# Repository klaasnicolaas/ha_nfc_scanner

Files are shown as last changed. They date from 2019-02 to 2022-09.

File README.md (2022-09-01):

# NFC Scanner :mag: for Home Assistant :house:

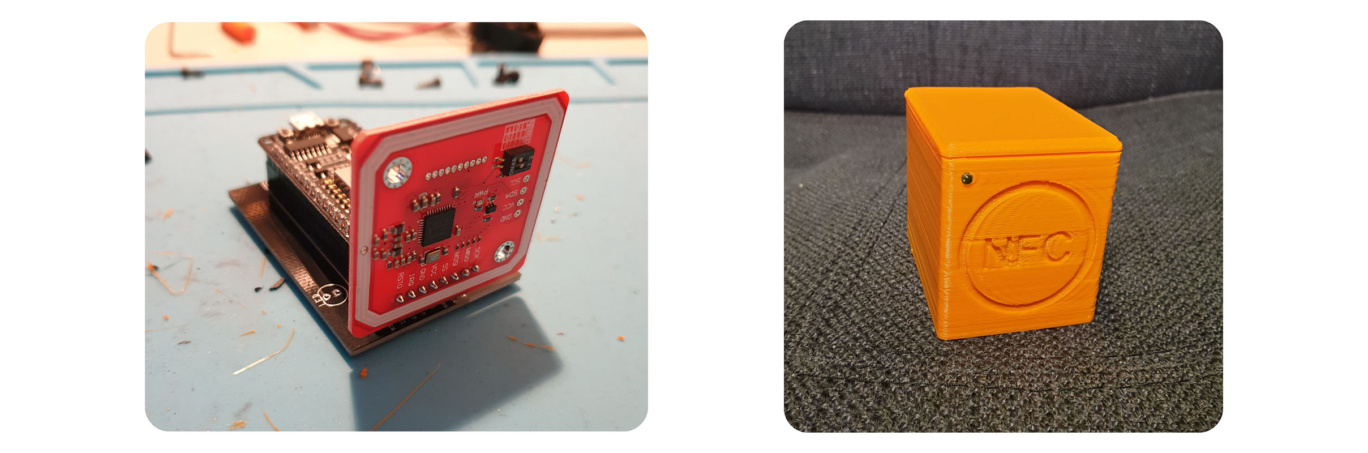
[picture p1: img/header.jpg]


## About

Imagine that you could start or stop everything with a NFC tag in Home Assistant :smile: Every time you hold an NFC tag against the scanner (and the UID of it is included in the list), there will be send an MQTT message to your broker and eventually to Home Assistant. With a LED you also get physical feedback, that the scanner has actually recognized your Tag. Recently I have added the feature to use Over The Air(OTA) updates, with password protection.

For the NFC scanner I designed a circuit board (PCB) and a 3D printed case.

- In the `case` folder you will find the required STL files.
- In the `pcb` folder you can find the Gerber files. Many people let their boards made by [Seeedstudio](https://www.seeedstudio.com/fusion_pcb.html) in Shenzhen.
- In the `img` folder some pictures of the project.

If you have suggestions or questions, open an **issue** or contribute via a **PR**!

### Schematic

Requirements:

- PN532 NFC RFID (Elechouse module v3) - [Banggood][pn532-bg-shop] or [AliExpress][pn532-ali-shop]
- ESP8266 (NodeMCU v1.0) - [Banggood][esp8266-bg-shop] or [AliExpress][esp8266-ali-shop]

| NFC reader | NodeMCU / ESP8266  |
|---|---|
| SS (CS) | D2 (GPIO4) |
| SCK | D5 (GPIO14) |
| MISO | D6 (GPIO12) |
| MOSI | D7 (GPIO13) |
| VCC | VCC (3V3) |
| GND | GND |

## How to setup

- You need Arduino IDE to configure some files, and use the serial monitor (other IDE's are okey).
- You need the `PN532`, `PubSubClient`, `SPI` and `ESP8266WiFi` library.

Further down this page you will find all information about which adjustments you have to make.

### NFC Tags

At `NUM_ACCEPTED_UIDS` you indicate how many NFC tags/cards you will use. Then enter the `UID` values of your NFC tags/cards and give each tag/card its own name. If you are going to make multiple nfc scanners, you can indicate in which room the scanner is present with the `LOCATION` variable.

```C++
#define NUM_ACCEPTED_UIDS 2 //<-----------------CHANGE THIS IF ADDING CARDS!!
NFCTag NFCTags[NUM_ACCEPTED_UIDS] = {
  // It is neccessary to account for UID length since a 7 byte ID could contain a 4 byte ID, which would cause a misfire
 //  #0    #1    #2    #3    #4    #5    #6   #Tagname
  {{0x00, 0x00, 0x00, 0x00, 0x00, 0x00, 0x00}, "Tag1", false, 0, false, {0}},
  {{0x00, 0x00, 0x00, 0x00, 0x00, 0x00, 0x00}, "Tag2", false, 0, false, {0}},
};

// Location of the NFC scanner
#define LOCATION "living_room"
```

#### Finding the UIDs

You can find your `UID` value in different ways, such as via your phone through certain apps from the app / play store. But to make it easy for yourself, it is possible to read only the UID tags / cards, via the same .ino script.

You start this mode by setting `readUIDMode` to true, in the **`ha_nfc_scanner.ino`** file.

```C++
// False wil start de main function, True will start the UID read script so you can find out wich UID's your NFC tags have on the serial monitor.
bool readUIDMode = true;
```

This way the MQTT and WIFI are switched off and you can read your UID values using the serial monitor.

### Credentials

Enter the details of your Wi-Fi network and login details of your MQTT client account and the IP address of the MQTT broker. Also provide a hostname and password for the Over The Air(OTA) feature.

```c++
// OTAupdate
#define OTA_HOSTNAME      ""
#define OTA_PASSWORD      ""

// Wi-Fi credentials
#define WIFI_SSID         ""
#define WIFI_PASSWORD     ""

// MQTT
#define MQTT_USERNAME     ""
#define MQTT_PASSWORD     ""
#define MQTT_SERVER       ""
#define MQTT_SERVER_PORT  1883
```

### Home Assistant - Binary Sensor

in Home Assistant we can create a binary sensor that will respond when a tag is recognized and is in the UID list.

To retrieve and use the results obtained with the NFC scanner into Home Assistant, please edit and add this snippet into your configuration. Make sure to replace `<CHIP_ID`, `<LOCATION>` and `<NFC_TAG_NAME>` with the values defined in `config.h`.

```yaml
# Example configuration.yaml entry
binary_sensor:
  - platform: mqtt
    name: 'NFC Tag 1'
    state_topic: '<CHIP_ID>/sensor/<LOCATION>/<NFC_TAG_NAME>/state'
    availability_topic: '<CHIP_ID>/availability'
  - platform: mqtt
    name: 'NFC Tag 2'
    state_topic: '<CHIP_ID>/sensor/<LOCATION>/<NFC_TAG_NAME>/state'
    availability_topic: '<CHIP_ID>/availability'
```

### PCB Design

Do you live in the Netherlands and you want a PCB? Contact me I have number of PCB's.

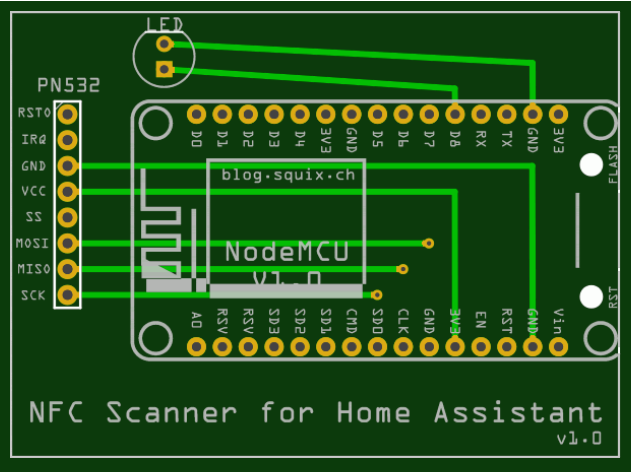
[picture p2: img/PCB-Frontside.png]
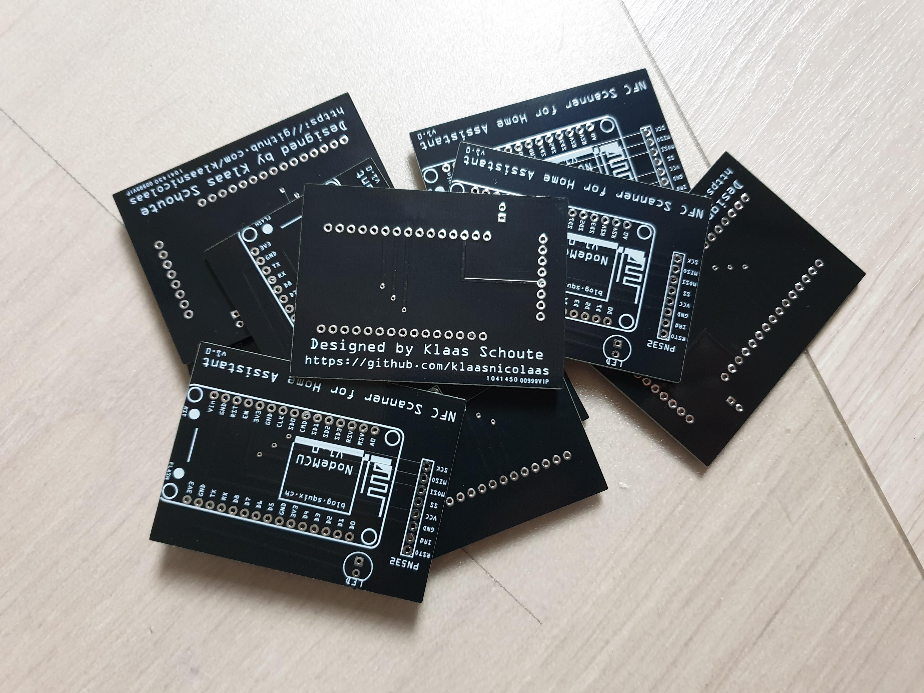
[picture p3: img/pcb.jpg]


## Troubleshooting

If you get an error, create then an **issue** so that I can sort things out for you. Below the solution for errors that I have encountered.

### Not Enough Space

If you get the error message `[ERROR]: Bad Answer: ERR: ERROR[4]: Not Enough Space`, change in the Arduino IDE the *Flash Size* to `4M (1M SPIFFS)`.

## Credits

A big :star: for [mertenats](https://github.com/mertenats/Open-Home-Automation), the script of this repo is based on his.

## Disclamer

We use aliexpress / banggood affiliate links for the components and the tools. Some Ad-blockers might block these links an thus they seem to appear broken. You will have to temporarely disable ad-blocker to open these links.

## License

MIT License

Copyright (c) 2019-2022 Klaas Schoute

Permission is hereby granted, free of charge, to any person obtaining a copy
of this software and associated documentation files (the "Software"), to deal
in the Software without restriction, including without limitation the rights
to use, copy, modify, merge, publish, distribute, sublicense, and/or sell
copies of the Software, and to permit persons to whom the Software is
furnished to do so, subject to the following conditions:

The above copyright notice and this permission notice shall be included in all
copies or substantial portions of the Software.

THE SOFTWARE IS PROVIDED "AS IS", WITHOUT WARRANTY OF ANY KIND, EXPRESS OR
IMPLIED, INCLUDING BUT NOT LIMITED TO THE WARRANTIES OF MERCHANTABILITY,
FITNESS FOR A PARTICULAR PURPOSE AND NONINFRINGEMENT. IN NO EVENT SHALL THE
AUTHORS OR COPYRIGHT HOLDERS BE LIABLE FOR ANY CLAIM, DAMAGES OR OTHER
LIABILITY, WHETHER IN AN ACTION OF CONTRACT, TORT OR OTHERWISE, ARISING FROM,
OUT OF OR IN CONNECTION WITH THE SOFTWARE OR THE USE OR OTHER DEALINGS IN THE
SOFTWARE.

[scanner-stack]: /img/nfc-scanner-stack.jpg

<!-- Hardware -->
[esp8266-bg-shop]: https://www.banggood.com/bang/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
[esp8266-ali-shop]: https://tc.tradetracker.net/?c=15640&m=12&a=417111&r=&u=%2Fitem%2F4000160133215.html
[pn532-bg-shop]: https://www.banggood.com/bang/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
[pn532-ali-shop]: https://tc.tradetracker.net/?c=15640&m=12&a=417111&r=&u=%2Fitem%2F1005001561633575.html

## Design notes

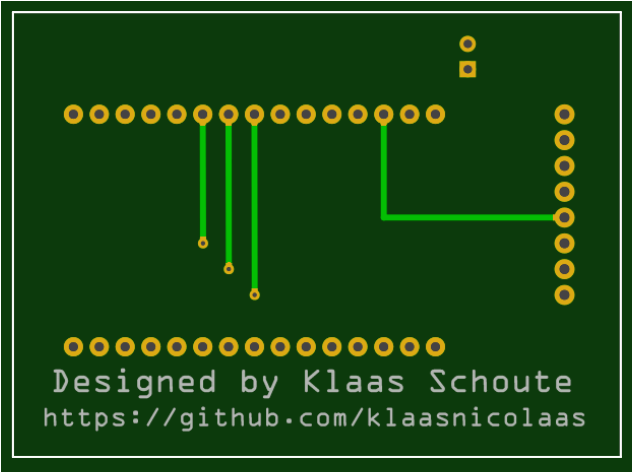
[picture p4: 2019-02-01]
img/PCB-Backside.png

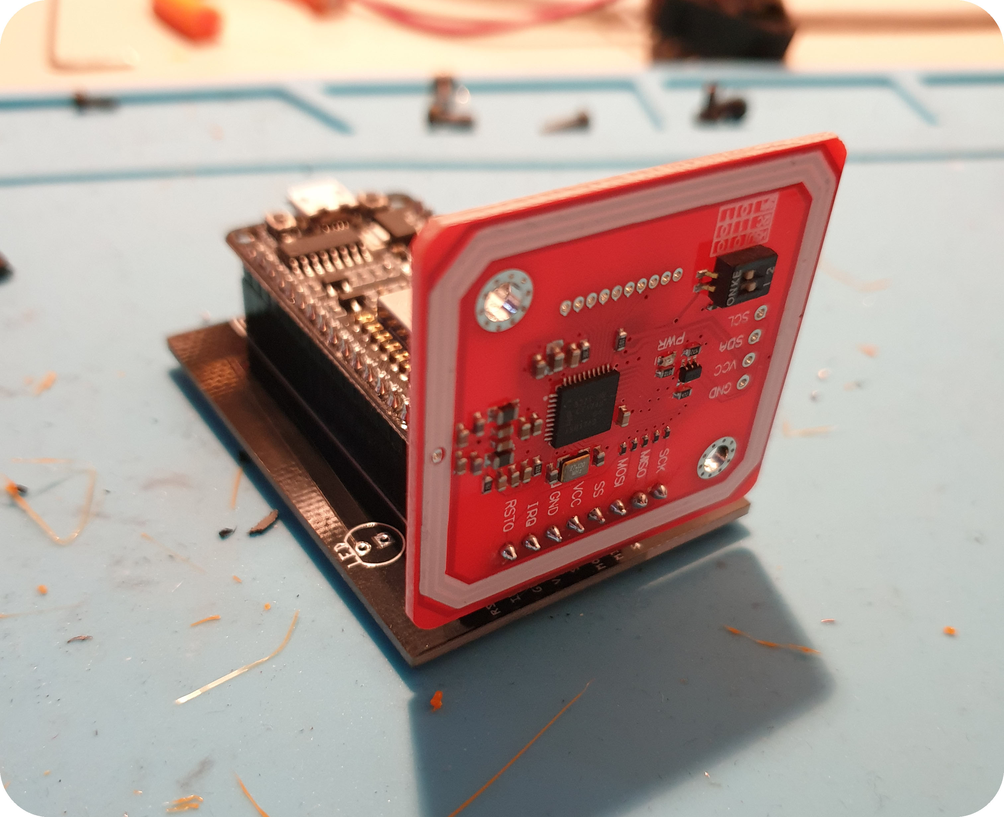
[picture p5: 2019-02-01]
img/nfc-scanner-stack.jpg

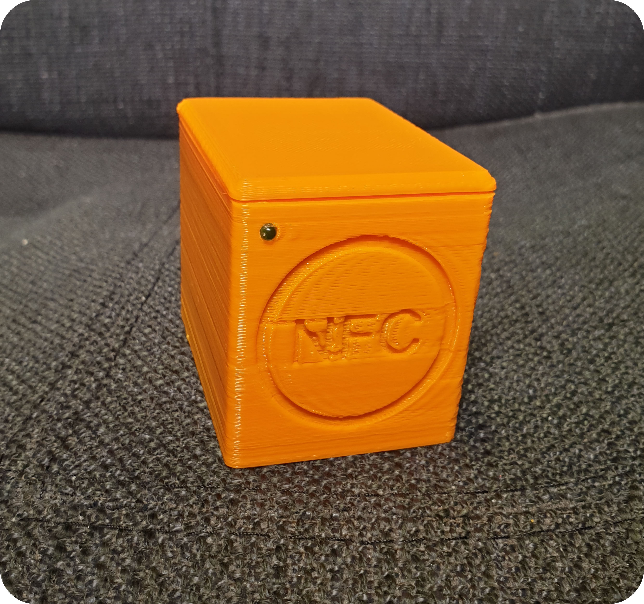
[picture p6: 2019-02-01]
img/case.jpg

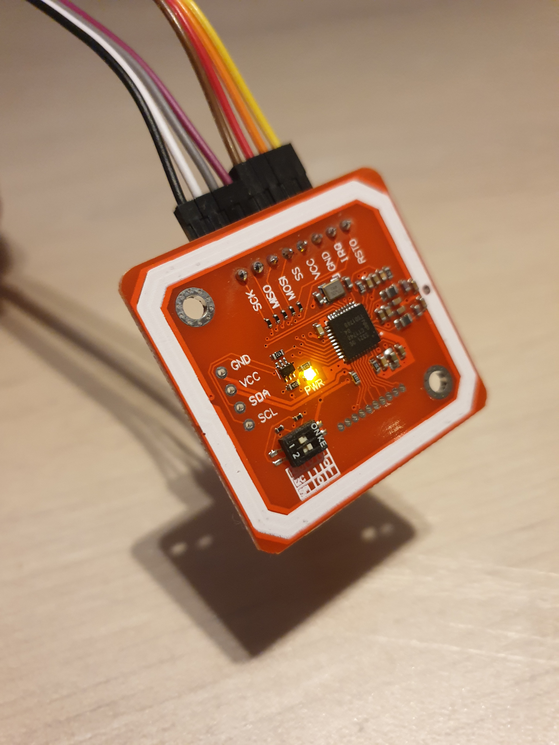
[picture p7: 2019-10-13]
img/pn532.jpg

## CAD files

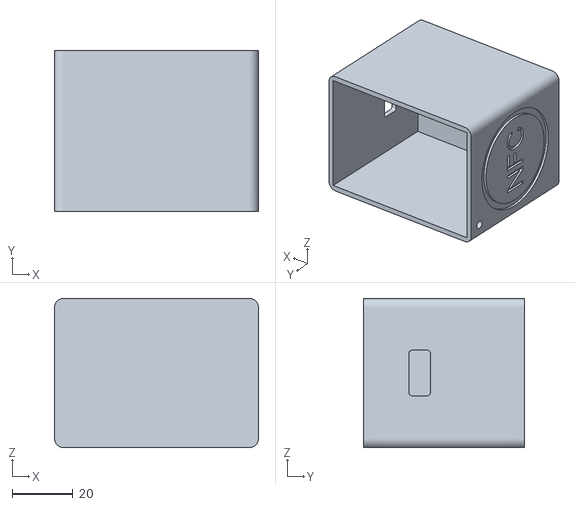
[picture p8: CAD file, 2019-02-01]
case/NFC Scanner box v1.1.stl
67.0 x 53.0 x 49.0

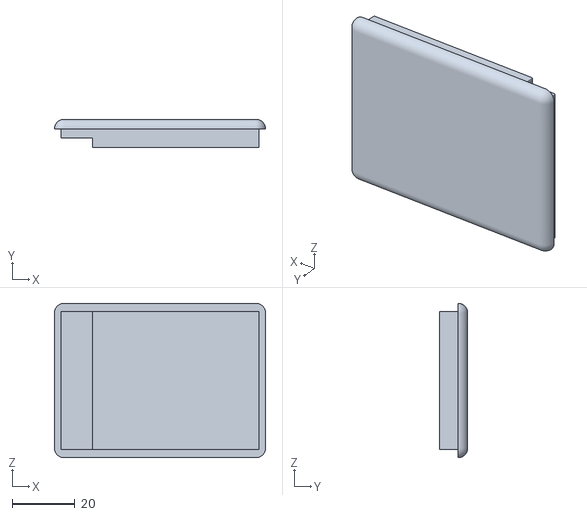
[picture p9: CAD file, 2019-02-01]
case/NFC Scanner box - Cover v1.3.stl
67.0 x 9.00 x 49.0

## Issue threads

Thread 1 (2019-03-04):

PCB to Germany

TheZoker, 2019-03-04:
Awesome NFC project!
I know not really an issue, but the best way to contact you

Just wondering if you would also send these PCBs that you made to Germany? 😃

klaasnicolaas, 2019-03-04:
You can contact me directly via Discord (Mister Nicolaz#7558), [Twitter](https://twitter.com/klaasnicolaas) or email on my Github profile.

Then we will see what is possible.

Closed 2019-03-05.

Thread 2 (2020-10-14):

NFCTag erro - Noob help

kekec777, 2020-10-14:
Hi

First i want to say , that im new to this , so please be patient with me :)

I want to make a nfc scanner and have bought :
PN532 NFC RFID (Elechouse module v3)
ESP8266 (NodeMCU v1.0)

and have printed the case in 3D.

BUT when i try to compile (in Arduino) this:

`#define NUM_ACCEPTED_UIDS 1 //<-----------------CHANGE THIS IF ADDING CARDS!!
NFCTag NFCTags[NUM_ACCEPTED_UIDS] = {
  // It is neccessary to account for UID length since a 7 byte ID could contain a 4 byte ID, which would cause a misfire
 //  #0    #1    #2    #3    #4    #5    #6   #Tagname
  {{0x00, 0x00, 0x00, 0x00, 0x00, 0x00, 0x01}, "Tag1", false, 0, false, {0}},
};

// send OFF payload after x ms
#define MAX_NON_DISCOVERED_PERIOD 500

// Location of the BLE scanner
#define LOCATION "living_room"

`

i get an error :
error: 'NFCTag' does not name a type
 NFCTag NFCTags[NUM_ACCEPTED_UIDS] = {
 ^
exit status 1
'NFCTag' does not name a type

I have added PN532 and PubSubClient in Arduino\libraries manually , but  SPI and ESP8266WiFi i couldt find?
I tried to search in Arduino Libraries and added some i thought sounded right.

Maybe a noob guide?
or any kind of input :)

thanks in advise

klaasnicolaas, 2020-10-21:
Unfortunately, I cannot help you with that at the moment, everything is still packed due to a move. As a result, I am now unable to debug it myself 😢

kekec777, 2020-12-15:
Thanks for the reply - and sorry for the late answer :)
I was also moving :)
When do you think you can debug it?

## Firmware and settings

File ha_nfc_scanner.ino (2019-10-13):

/*
  NFC Scanner for Home Assistant
  
  Libraries:
    - PubSubClient: https://github.com/knolleary/pubsubclient
    - PN532:        https://github.com/Seeed-Studio/PN532

  Release Notes:
  Klaas S. - V1.2 - 10.2019
  - Add OTA update feature

  Klaas S. - V1.1 - 02.2019
  - By means of an LED you can now see if the ESP recognizes an NFC tag.
  - Fix use of 7 bytes nfc tags.
  - Add option to use reading UID's only or not.
  
  Samuel M. - v1.0 - 02.2018
  - Initial script that is made by: https://github.com/mertenats/open-home-automation
*/

typedef struct {
  uint8_t uid[8];
  String  tagName;
  bool    isDiscovered;
  long    lastDiscovery;
  bool    toNotify;
  char    mqttTopic[48];
} NFCTag;

#include "config.h"
#include <ESP8266WiFi.h>
#include <ArduinoOTA.h>
#include <SPI.h>
#include <PN532_SPI.h>
#include "PN532.h"        // https://github.com/Seeed-Studio/PN532
#include <PubSubClient.h> // https://github.com/knolleary/pubsubclient

#if defined(DEBUG_SERIAL)
#define     DEBUG_PRINT(x)    Serial.print(x)
#define     DEBUG_PRINTLN(x)  Serial.println(x)
#else
#define     DEBUG_PRINT(x)
#define     DEBUG_PRINTLN(x)
#endif

WiFiClient    wifiClient;
PubSubClient  mqttClient(wifiClient);
PN532_SPI     pn532spi(SPI, 4);
PN532         nfc(pn532spi);

int ledPin = 15;
// False wil start de main function, True will start the UID read script so you can find out wich UID's your NFC tags have on the serial monitor.
bool readUIDMode = false;

///////////////////////////////////////////////////////////////////////////
//   Read NFC as sensor for HA 
///////////////////////////////////////////////////////////////////////////
void readNFCTag() {
  uint8_t uid[] = { 0, 0, 0, 0, 0, 0, 0, 0 };  // Buffer to store the returned UID
  uint8_t uidLength; // Length of the UID (4 or 7 bytes depending on ISO14443A card type)
  
  if (nfc.readPassiveTargetID(PN532_MIFARE_ISO14443A, uid, &uidLength)) {
    for (uint8_t i = 0; i < NUM_ACCEPTED_UIDS; i++) {
      if (strcmp((char *)uid, (char *)NFCTags[i].uid) == 0) {
        if (!NFCTags[i].isDiscovered) {
          NFCTags[i].isDiscovered = true;
          NFCTags[i].toNotify = true;
          digitalWrite(ledPin, HIGH);
        }
        NFCTags[i].lastDiscovery = millis();
        break;
      }
    }
  }
  
  for (uint8_t i = 0; i < NUM_ACCEPTED_UIDS; i++) {
    if (NFCTags[i].isDiscovered == true && NFCTags[i].lastDiscovery + MAX_NON_DISCOVERED_PERIOD < millis()) {
      NFCTags[i].isDiscovered = false;
      NFCTags[i].toNotify = true;
      digitalWrite(ledPin, LOW);
    }
  }
}

///////////////////////////////////////////////////////////////////////////
//   Read NFC UID's  
///////////////////////////////////////////////////////////////////////////
void readUID() {
  boolean success;
  uint8_t uidLength;   // Length of the UID (4 or 7 bytes depending on ISO14443A card type)
  uint8_t uid[] = { 0, 0, 0, 0, 0, 0, 0 };  // Buffer to store the returned UID

  // Wait for an ISO14443A type cards (Mifare, etc.).  When one is found
  // 'uid' will be populated with the UID, and uidLength will indicate
  // if the uid is 4 bytes (Mifare Classic) or 7 bytes (Mifare Ultralight)
  success = nfc.readPassiveTargetID(PN532_MIFARE_ISO14443A, &uid[0], &uidLength);

  if (success) {
    digitalWrite(ledPin, HIGH);
    Serial.println("\n-----------\n");
    Serial.println("Found a card!");
    Serial.print("UID Length: ");
    Serial.print(uidLength, DEC);
    Serial.println(" bytes");
    Serial.print("UID Value: ");
    delay(1000);
    digitalWrite(ledPin, LOW);

    for (uint8_t i=0; i < uidLength; i++) {
      Serial.print(" 0x");
      Serial.print(uid[i], HEX);
    }

    // wait until the card is taken away
    while (nfc.readPassiveTargetID(PN532_MIFARE_ISO14443A, &uid[0], &uidLength)) {
      yield(); //let ESPcore handle wifi stuff
    }
    
    Serial.println("\n-----------\n");
  }
  else yield(); // PN532 probably timed out waiting for a card.. let's let the ESPcore handle wifi stuff
}
///////////////////////////////////////////////////////////////////////////
//   WiFi
///////////////////////////////////////////////////////////////////////////
/*
   Function called to handle WiFi events
*/
void handleWiFiEvent(WiFiEvent_t event) {
  switch (event) {
    case WIFI_EVENT_STAMODE_GOT_IP:
      DEBUG_PRINTLN(F("INFO: Connection successful to the Wi-Fi AP"));
      DEBUG_PRINT(F("INFO: IP address: "));
      DEBUG_PRINTLN(WiFi.localIP());
      break;
    case WIFI_EVENT_STAMODE_DISCONNECTED:
      DEBUG_PRINTLN(F("ERROR: Connection lost from the Wi-Fi AP"));
      /*
         TODO: Doing something smarter than rebooting the device
      */
      delay(5000);
      ESP.restart();
      break;
    default:
      DEBUG_PRINT(F("INFO: WiFi event: "));
      DEBUG_PRINTLN(event);
      break;
  }
}

/*
   Function called to setup the connection to the WiFi AP
*/
void setupWiFi() {
  DEBUG_PRINT(F("INFO: WiFi connecting to: "));
  DEBUG_PRINTLN(WIFI_SSID);

  delay(10);

  WiFi.mode(WIFI_STA);
  WiFi.onEvent(handleWiFiEvent);
  WiFi.begin(WIFI_SSID, WIFI_PASSWORD);

  randomSeed(micros());
}

///////////////////////////////////////////////////////////////////////////
//   Arduino OTA
///////////////////////////////////////////////////////////////////////////
void setupOTA() {  
  // Hostname defaults to esp8266-[ChipID]
  ArduinoOTA.setHostname(OTA_HOSTNAME);

  // No authentication by default
  ArduinoOTA.setPassword(OTA_PASSWORD);
  
  ArduinoOTA.onStart([]() {
    String type;
    if (ArduinoOTA.getCommand() == U_FLASH)
      type = "sketch";
    else // U_SPIFFS
      type = "filesystem";

    // NOTE: if updating SPIFFS this would be the place to unmount SPIFFS using SPIFFS.end()
    Serial.println("Start updating " + type);
  });
  
  ArduinoOTA.onEnd([]() {
    Serial.println("\nEnd");
  });
  
  ArduinoOTA.onProgress([](unsigned int progress, unsigned int total) {
    Serial.printf("Progress: %u%%\r", (progress / (total / 100)));
  });
  
  ArduinoOTA.onError([](ota_error_t error) {
    Serial.printf("Error[%u]: ", error);
    if (error == OTA_AUTH_ERROR) Serial.println("Auth Failed");
    else if (error == OTA_BEGIN_ERROR) Serial.println("Begin Failed");
    else if (error == OTA_CONNECT_ERROR) Serial.println("Connect Failed");
    else if (error == OTA_RECEIVE_ERROR) Serial.println("Receive Failed");
    else if (error == OTA_END_ERROR) Serial.println("End Failed");
  });
  
  ArduinoOTA.begin();
  Serial.println("Ready");
  Serial.print("IP address: ");
  Serial.println(WiFi.localIP());
}

///////////////////////////////////////////////////////////////////////////
//   MQTT
///////////////////////////////////////////////////////////////////////////
volatile unsigned long lastMQTTConnection = 0;
char MQTT_CLIENT_ID[7] = {0};
char MQTT_AVAILABILITY_TOPIC[sizeof(MQTT_CLIENT_ID) + sizeof(MQTT_AVAILABILITY_TOPIC_TEMPLATE) - 2] = {0};
/*
  Function called to publish to a MQTT topic with the given payload
*/
void publishToMQTT(char* p_topic, char* p_payload) {
  if (mqttClient.publish(p_topic, p_payload, true)) {
    DEBUG_PRINT(F("INFO: MQTT message published successfully, topic: "));
    DEBUG_PRINT(p_topic);
    DEBUG_PRINT(F(", payload: "));
    DEBUG_PRINTLN(p_payload);
  } else {
    DEBUG_PRINTLN(F("ERROR: MQTT message not published, either connection lost, or message too large. Topic: "));
    DEBUG_PRINT(p_topic);
    DEBUG_PRINT(F(" , payload: "));
    DEBUG_PRINTLN(p_payload);
  }
}
/*
  Function called to connect/reconnect to the MQTT broker
*/
void connectToMQTT() {
  if (!mqttClient.connected()) {
    if (lastMQTTConnection < millis()) {
      if (mqttClient.connect(MQTT_CLIENT_ID, MQTT_USERNAME, MQTT_PASSWORD, MQTT_AVAILABILITY_TOPIC, 0, 1, MQTT_PAYLOAD_UNAVAILABLE)) {
        DEBUG_PRINTLN(F("INFO: The client is successfully connected to the MQTT broker"));
        publishToMQTT(MQTT_AVAILABILITY_TOPIC, MQTT_PAYLOAD_AVAILABLE);
      } else {
        DEBUG_PRINTLN(F("ERROR: The connection to the MQTT broker failed"));
        DEBUG_PRINT(F("INFO: MQTT username: "));
        DEBUG_PRINTLN(MQTT_USERNAME);
        DEBUG_PRINT(F("INFO: MQTT password: "));
        DEBUG_PRINTLN(MQTT_PASSWORD);
        DEBUG_PRINT(F("INFO: MQTT broker: "));
        DEBUG_PRINTLN(MQTT_SERVER);
      }
      lastMQTTConnection = millis() + MQTT_CONNECTION_TIMEOUT;
    }
  }
}

///////////////////////////////////////////////////////////////////////////
//   SETUP() & LOOP()
///////////////////////////////////////////////////////////////////////////
void setup() {
#if defined(DEBUG_SERIAL)
  Serial.begin(115200);
#endif

  pinMode(ledPin, OUTPUT);
  setupOTA();

  if (readUIDMode == false) {
    setupWiFi();
  }

  nfc.begin();
 
  uint32_t nfcReaderFirmwareVersion = nfc.getFirmwareVersion();
  if (!nfcReaderFirmwareVersion) {
    DEBUG_PRINTLN(F("ERROR: Didn't find PN53x board"));
    while (1); // halt
  }
  
  // configure board to read RFID tags
  nfc.SAMConfig();
  
  sprintf(MQTT_CLIENT_ID, "%06X", ESP.getChipId());
  sprintf(MQTT_AVAILABILITY_TOPIC, MQTT_AVAILABILITY_TOPIC_TEMPLATE, MQTT_CLIENT_ID);

  DEBUG_PRINT(F("INFO: MQTT availability topic: "));
  DEBUG_PRINTLN(MQTT_AVAILABILITY_TOPIC);

  char mqttTopic[sizeof(MQTT_CLIENT_ID) + sizeof(MQTT_SENSOR_TOPIC_TEMPLATE) + sizeof(LOCATION) + 12 - 4] = {0};
  for (uint8_t i = 0; i < NUM_ACCEPTED_UIDS; i++) {
      char tmpTagName[sizeof(NFCTags[i].tagName)] = {0};
      NFCTags[i].tagName.toCharArray(tmpTagName, sizeof(tmpTagName));
      sprintf(mqttTopic, MQTT_SENSOR_TOPIC_TEMPLATE, MQTT_CLIENT_ID, LOCATION, tmpTagName);
      memcpy(NFCTags[i].mqttTopic, mqttTopic, sizeof(mqttTopic) + 1);
      DEBUG_PRINT(F("INFO: MQTT sensor topic: "));
      DEBUG_PRINTLN(NFCTags[i].mqttTopic);
  }
  
  mqttClient.setServer(MQTT_SERVER, MQTT_SERVER_PORT);
  if (readUIDMode == false) {
    connectToMQTT();
  }
}

void loop() {
  ArduinoOTA.handle();

  yield();

  if (readUIDMode == true) {
    readUID();
  } else if (readUIDMode == false) {
    connectToMQTT();
    mqttClient.loop();
    readNFCTag();
  }

  yield();

  for (uint8_t i = 0; i < NUM_ACCEPTED_UIDS; i++) {
    if (NFCTags[i].toNotify) {
      if (NFCTags[i].isDiscovered) {
        publishToMQTT(NFCTags[i].mqttTopic, MQTT_PAYLOAD_ON);
      } else {
        publishToMQTT(NFCTags[i].mqttTopic, MQTT_PAYLOAD_OFF);
      }
      NFCTags[i].toNotify = false;
    }
  }
  
  yield();
}

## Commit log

2019-02-01 :tada: Adding Gerber files from PCB V1.0
2019-02-01 :tada: Adding STL case files
    [NFC Scanner box - Cover v1.3.stl, NFC Scanner box v1.1.stl]
2019-02-01 :tada: Adding PCB Backside
2019-10-13 :sparkles: Add arduino OTA feature to the project
